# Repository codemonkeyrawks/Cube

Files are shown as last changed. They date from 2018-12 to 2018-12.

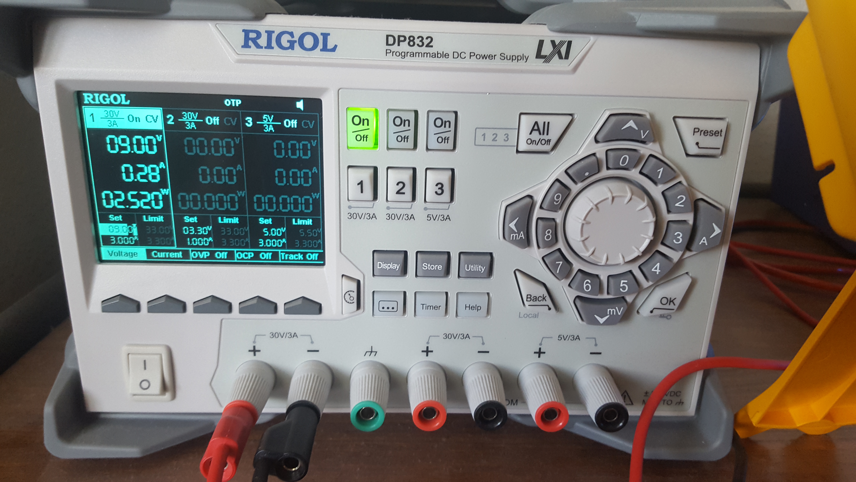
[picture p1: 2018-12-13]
Pics/Issue1PS.jpg

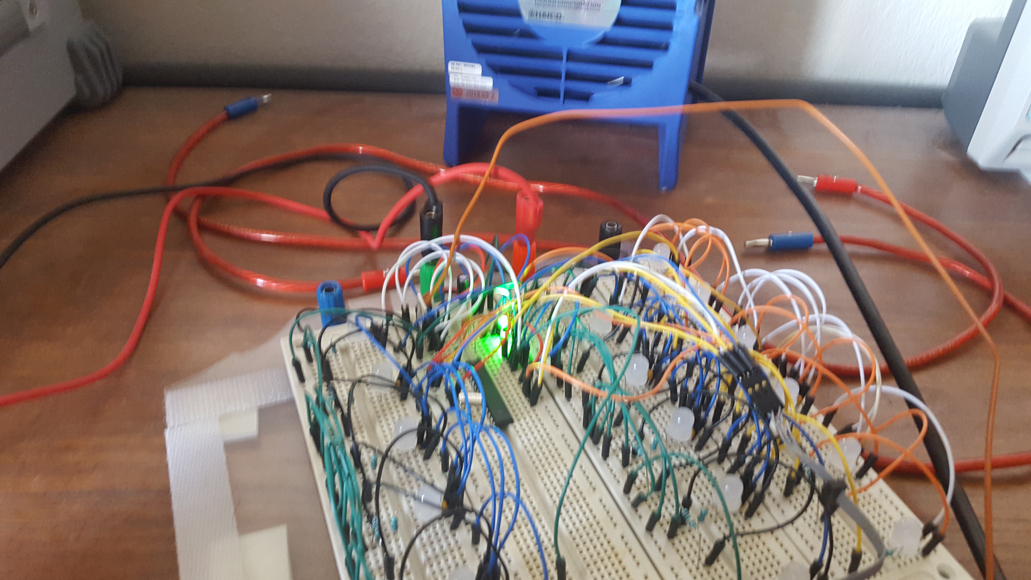
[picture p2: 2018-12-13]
Pics/Issue1Cube.jpg

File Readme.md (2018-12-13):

Led Cube Project:

#### Folder Structure:

    Main Project:
    /CAD - CAD Files for the Cube
    /Circuit - Electrical Hookup Guide
    /Code - TFT Display, Music Board, Lights Code
    /Pics - Pictures of the Build
    /Presentation - Slide Show of Build
    readme.md - Getting Started Guide
    
    Testing:
    .travis.yml - Used for Testing Only (Checks if Code Passes or Not)

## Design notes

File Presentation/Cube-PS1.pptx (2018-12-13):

## Led CUBE Project

By: Brian Holaday

## Past PROJECTS

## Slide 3

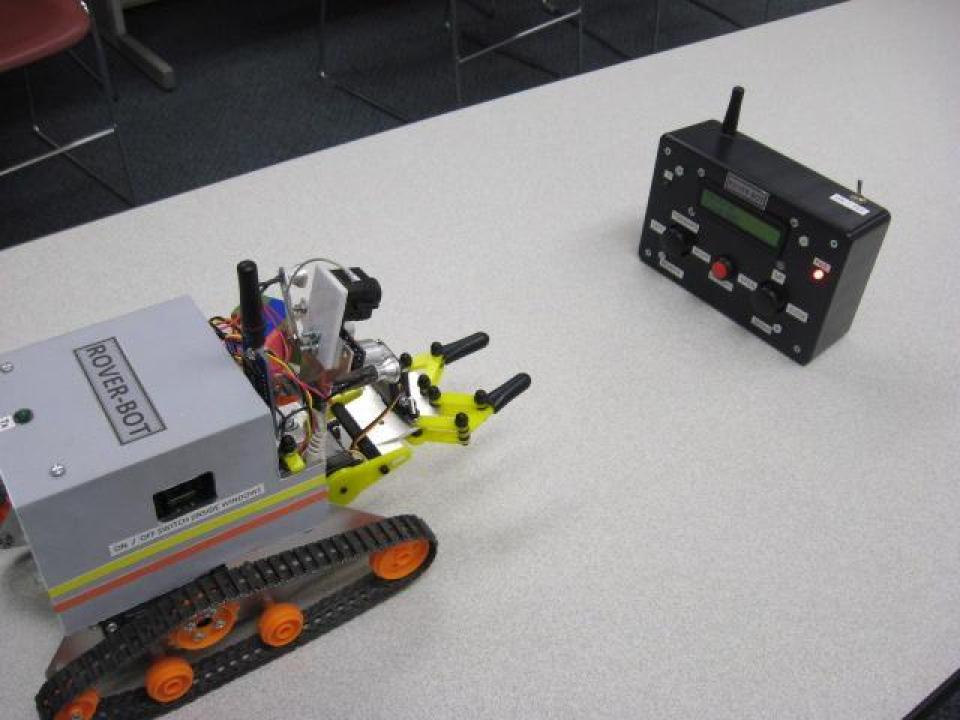
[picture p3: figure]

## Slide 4

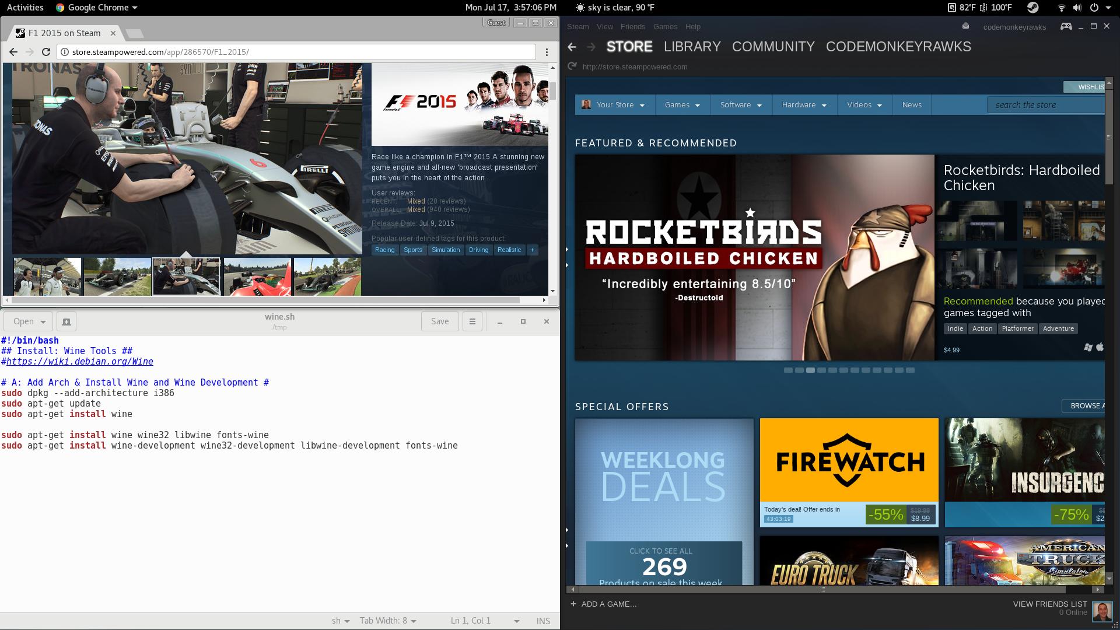
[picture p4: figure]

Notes: https://www.youtube.com/watch?v=Otk6VTVJKBU&list=PL-xZsBalytNA71DNhKQv3fKPJpMA8v7VH&t=0s&index=8 1:34

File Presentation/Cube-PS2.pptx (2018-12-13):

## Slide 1

Led Cube

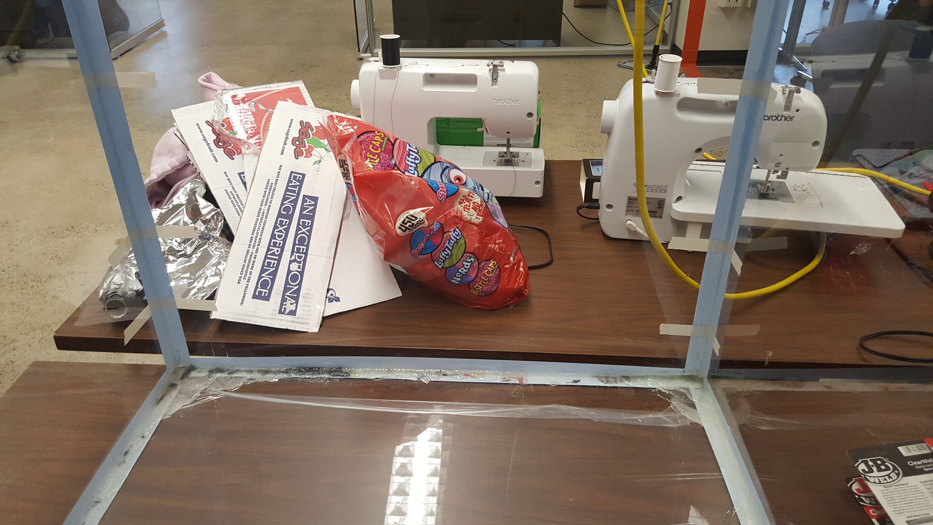
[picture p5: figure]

Description:
Build a 8x8x8 Box with Ping Pong Balls

Brian Holaday

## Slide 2

Led Cube - Problem #1

Problem: Overload on Temperature due to Current

Solution: 6 Volts x 20mA = 120mW (24° C)

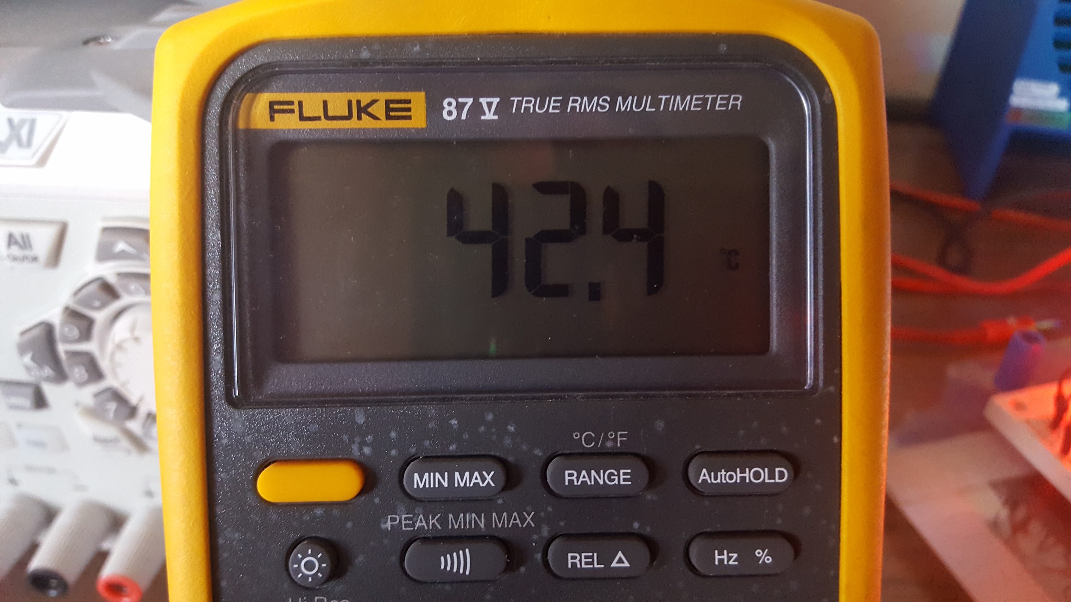
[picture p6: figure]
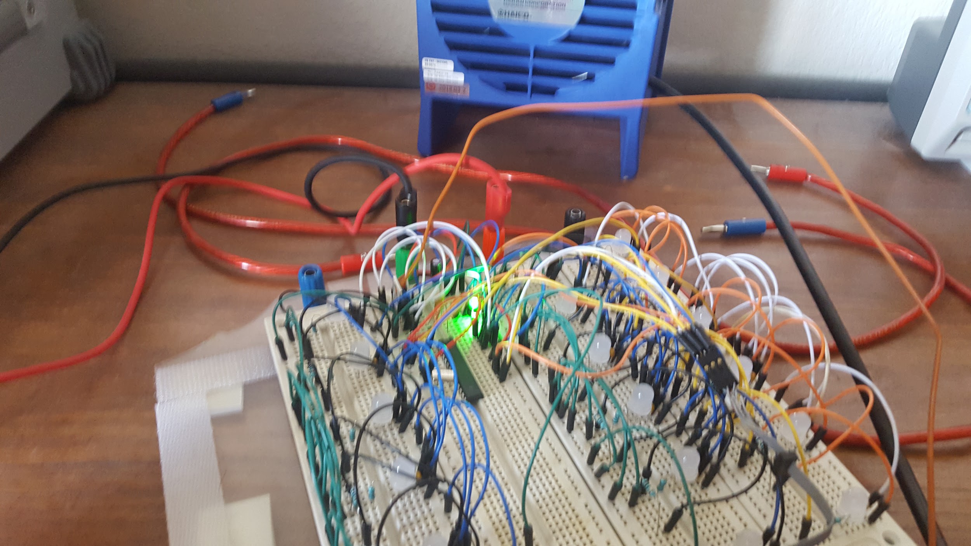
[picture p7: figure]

Brian Holaday

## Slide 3

Led Cube - Problem #2

Problem: Timing is Key with Shift Registers

Solution: Added: RC Filter and R Overload

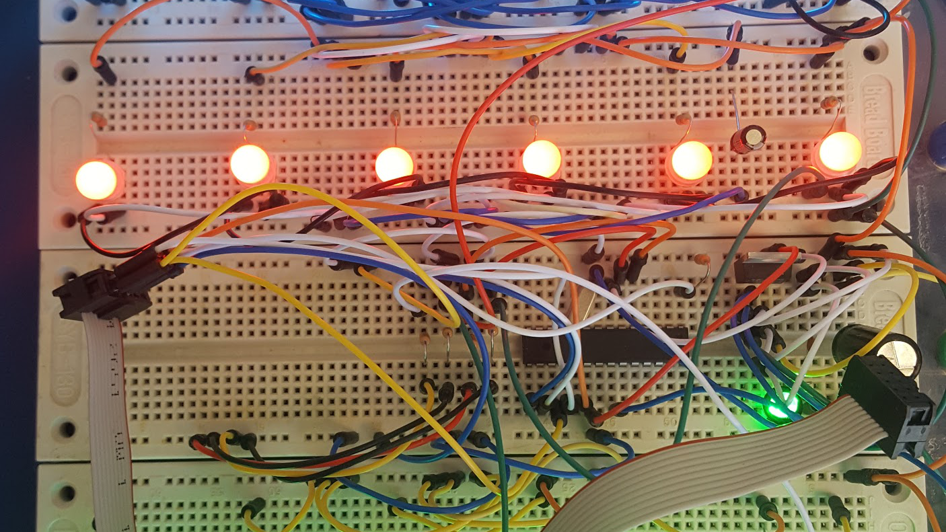
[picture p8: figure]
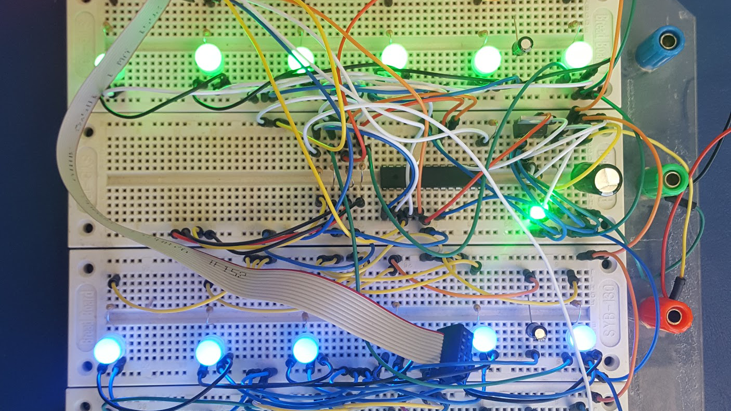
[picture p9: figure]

Brian Holaday

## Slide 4

Led Cube - Problem #3

Problem: Brightness Adjustment using PWM

Solution: Tweaked R Value on LED’s for Max Bright

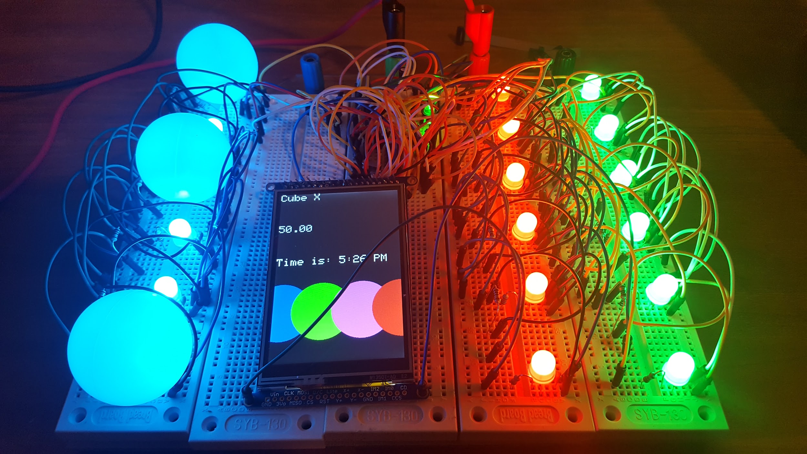
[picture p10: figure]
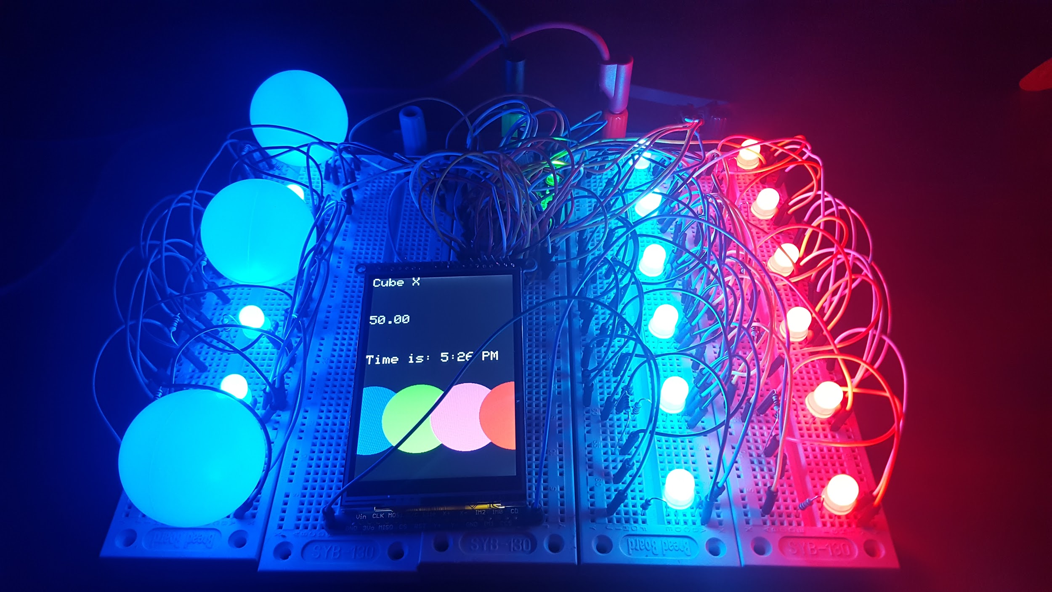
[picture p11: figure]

Brian Holaday

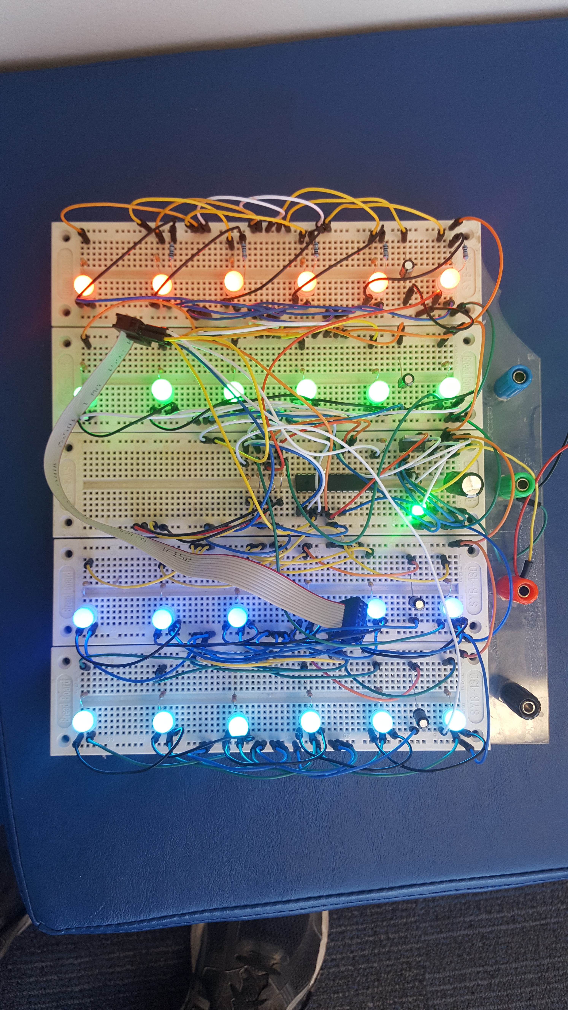
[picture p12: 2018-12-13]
Pics/Led-A.jpg

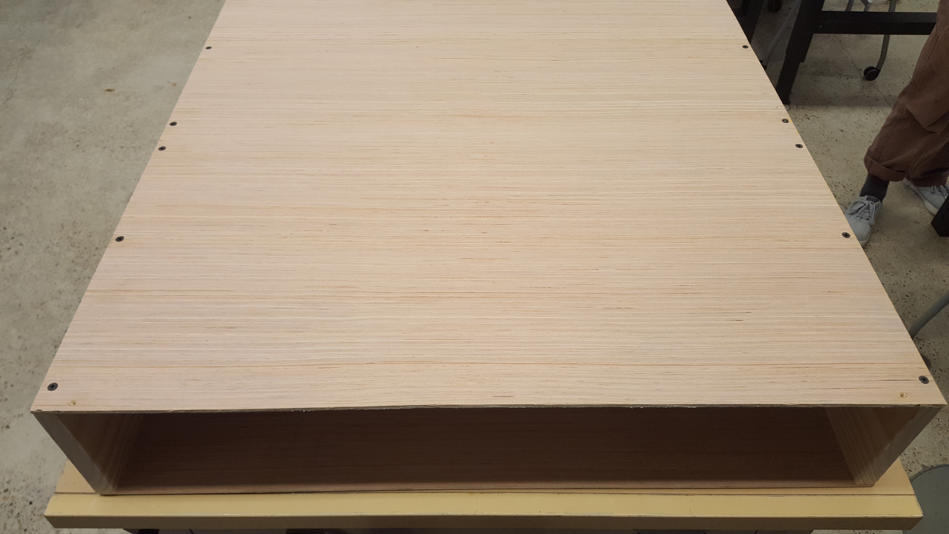
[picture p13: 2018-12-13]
Pics/Base-A.jpg

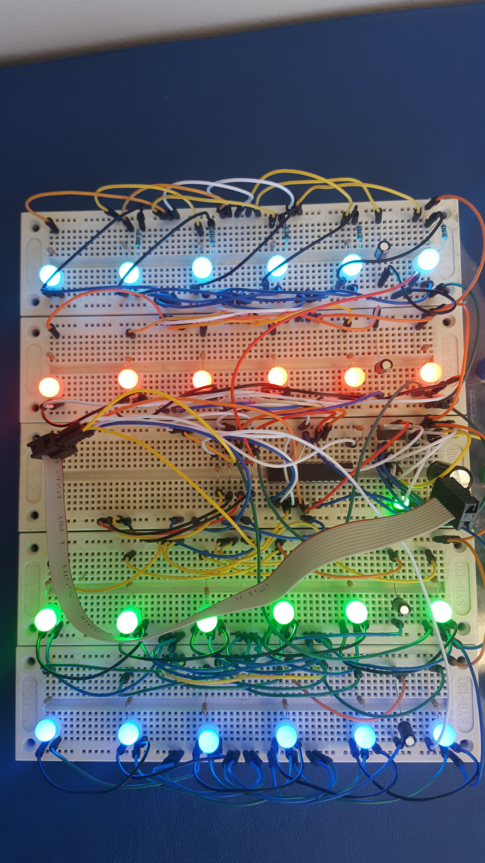
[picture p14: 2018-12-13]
Pics/Led-B.jpg

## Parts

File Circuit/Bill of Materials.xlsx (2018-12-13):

Bill of Materials
Item | Quantity | Cost | Total Cost
Total Cube Cost | 1 | $182.22 | $372.22
Phase #1
LT1083-5 - 5V Regulator (http://www.analog.com/media/en/technical-documentation/data-sheets/1083ffe.pdf) | 8 | $4.20 | $0.00
22uF Tant Cap (https://www.digikey.com/product-detail/en/199D226X9016D1V1E3/718-1182-ND/1559821/?itemSeq=273156367) | 1 | $1.72 | $1.72
10uF Film Cap (https://www.digikey.com/product-detail/en/panasonic-electronic-components/ECA-1HHG100/P5567-ND/245166) | 1 | $0.23 | $0.23
LED | 1 | $0.23 | $0.23 | --
LR1F1K0 - 1K 0.6 W Resistor (https://www.digikey.com/product-detail/en/te-connectivity-passive-product/LR1F1K0/A105951CT-ND/3477524) | 1 | $0.12 | $0.12
3.5mm Jack (https://www.digikey.com/product-detail/en/PJ-002A/CP-002A-ND/96962/?itemSeq=273156850) | 1 | $0.61 | $0.61 | --
Switch - 5A - Slide (https://www.digikey.com/product-detail/en/48ASSP1S3M1QAT/GH7809-ND/2677850/?itemSeq=273157120) | 1 | $3.95 | $3.95 | --
AC/DC Wall Adapter (https://www.digikey.com/product-detail/en/mean-well-usa-inc/SGA60U12-P1J/1866-4550-ND/7706701) | 1 | $24.67 | $24.67 | --
AM2320 - Temp & Humid (https://www.adafruit.com/product/3721) | 2 | $3.95 | $7.90
TMP36 - Temp Sensor (https://www.digikey.com/product-detail/en/analog-devices-inc/TMP36GT9Z/TMP36GT9Z-ND/820404) | 4 | $1.48 | $5.92
5V PWM with Tach FAN (https://www.digikey.com/product-detail/en/delta-electronics/ASB0305HP-00CP4/603-2070-ND/7403227) | 2 | $9.36 | $18.72 | -
Phase #2
ATMEGA 328P-PU (https://www.digikey.com/product-detail/en/microchip-technology/ATMEGA328P-PU/ATMEGA328P-PU-ND/1914589) | 4 | $2.14 | $0.00
PL9823 F8 RGB (https://www.ebay.com/itm/5-1000pcs-DC5V-PL9823-F5-5mm-F8-8mm-round-hat-RGB-LED-Frosted-LED-Chips-P9823/152637379573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) | 520 | $0.16 | $83.20
0.1uF Ceramic Cap (https://www.digikey.com/product-detail/en/K104K15X7RF5TL2/BC1084CT-ND/286706/?itemSeq=273156178) | 520 | 0.06 | $31.20
LR1F10R - 10 Ohm 0.6 W Resistor (https://www.digikey.com/product-detail/en/te-connectivity-passive-product/LR1F10R/A105948CT-ND/3477520) | 520 | $0.02 | $11.17
LR1F100R - 100 Ohm 0.6 W Resistor (https://bit.ly/2EifDAj) | 520 | $0.02 | $11.17
Ping Pong Balls (https://www.amazon.com/Assortmart-Washable-Plastic-Balls-Gross/dp/B0038HUS40) | 4 | $9.29 | $37.16
3/32 Heatshrink Tubing - 100FT (https://bit.ly/2yAaf5B) | 1 | $8.29 | $8.29
Phase #3
LCD Display - 8 Bit 3.5 TFT (https://www.adafruit.com/product/2050) | 1 | $39.95 | $39.95
VS1053 MicroSD Board (https://www.digikey.com/product-detail/en/adafruit-industries-llc/1381/1528-1055-ND/5011071) | 1 | $24.95 | $24.95
22uF Tant Cap (https://www.digikey.com/product-detail/en/199D226X9016D1V1E3/718-1182-ND/1559821/?itemSeq=273156367) | 1 | $1.72 | $1.72
10uF Film Cap (https://www.digikey.com/product-detail/en/panasonic-electronic-components/ECA-1HHG100/P5567-ND/245166) | 1 | $0.23 | $0.23
5mm LED - RGB (https://www.adafruit.com/product/159) | 1 | $0.23 | $0.23
LR1F300R - 330 Ohm 0.6 W Resistor (https://www.digikey.com/product-detail/en/te-connectivity-passive-product/LR1F330R/A105958CT-ND/3477536) | 1 | $0.12 | $0.12
Stereo Speakers - 4 ohms (https://www.digikey.com/product-detail/en/adafruit-industries-llc/1669/1528-1847-ND/6612447) | 1 | $7.50 | $7.50
SD Card - 16GB (https://amzn.to/2IVJtcH) | 3 | $7.12 | $21.36
FeatherWing Ethernet Board (https://bit.ly/2Cc0NbM) | 1 | 19.95 | $19.95
2.8W Amp Breakout Board (https://bit.ly/2NHreZj) | 1 | 9.95 | $9.95

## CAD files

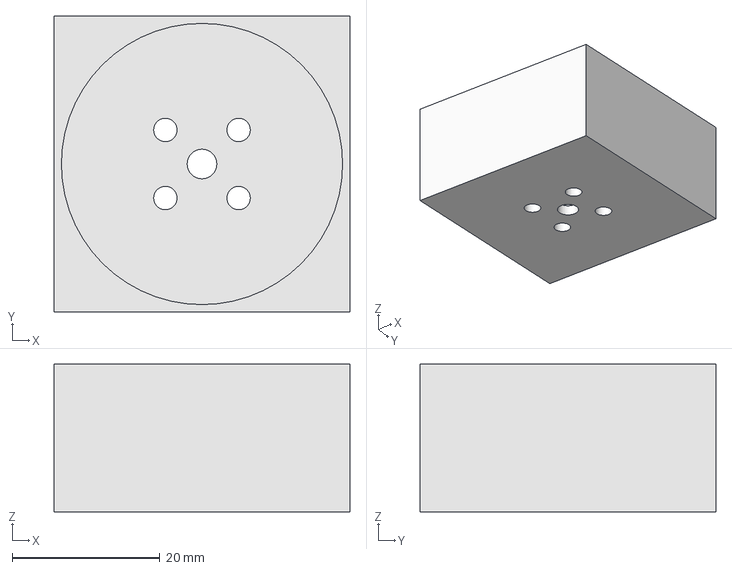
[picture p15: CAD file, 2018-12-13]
CAD/Jig.fcstd
40.0 x 40.0 x 20.0 mm

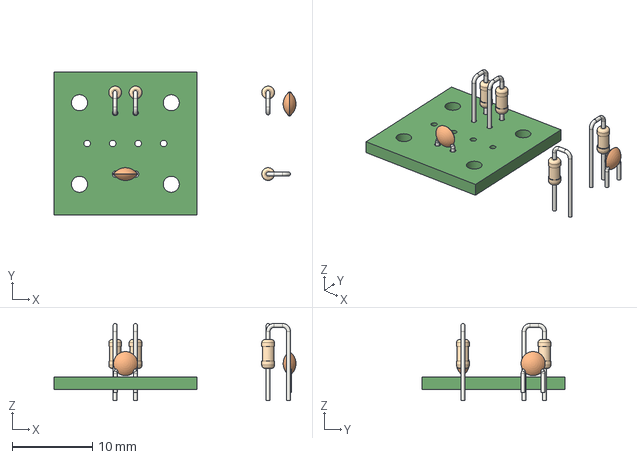
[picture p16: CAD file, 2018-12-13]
Circuit/Balls/Cube-Balls.step
30.1 x 17.8 x 9.60 mm

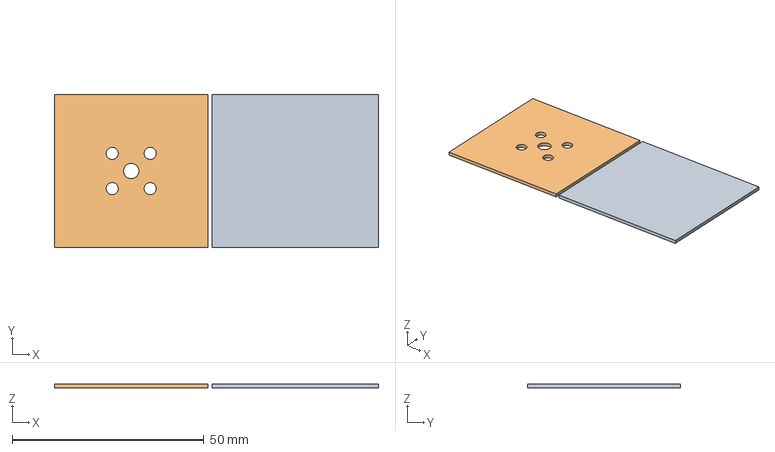
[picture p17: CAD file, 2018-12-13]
CAD/PanelKit.fcstd
84.5 x 40.0 x 1.00 mm

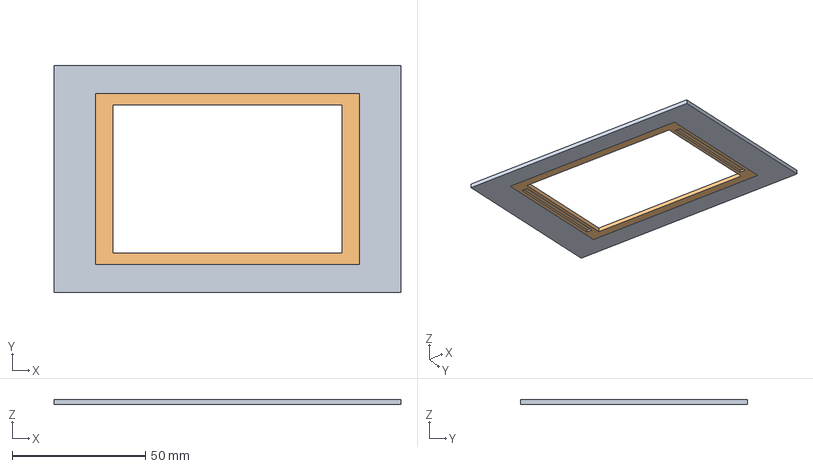
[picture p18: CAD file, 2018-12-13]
CAD/TFT.fcstd
130.0 x 85.0 x 2.00 mm

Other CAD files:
CAD/Jig.stl
CAD/PanelKit.stl
CAD/TFT.stl

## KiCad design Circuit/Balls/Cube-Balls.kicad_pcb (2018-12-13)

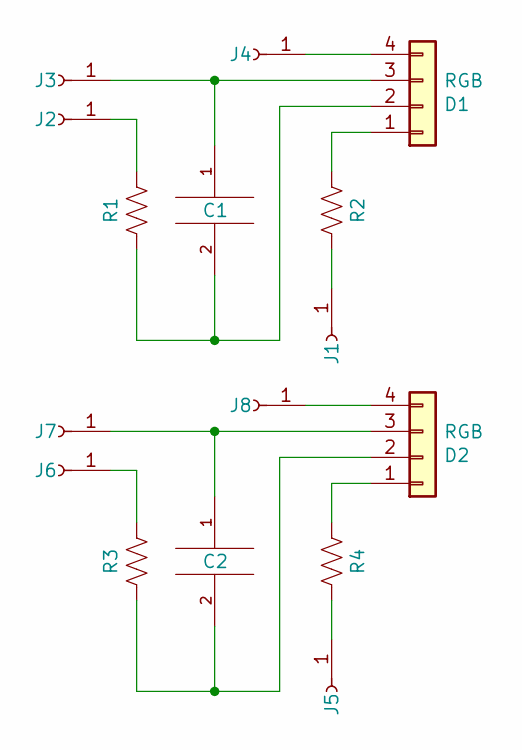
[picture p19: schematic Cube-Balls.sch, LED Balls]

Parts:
C1, C2: 0.1uF; R_Axial_DIN0204_L3.6mm_D1.6mm_P2.54mm_Vertical
D1, D2: RGB; SolderWirePad_1x04_P3.175mm_Drill0.8mm
J1, J5: IN; SolderWirePad_1x01_Drill1mm
J2, J6: VCC; SolderWirePad_1x01_Drill1mm
J3, J7: GND; SolderWirePad_1x01_Drill1mm
J4, J8: OUT; SolderWirePad_1x01_Drill1mm
R1, R3: 100; R_Axial_DIN0204_L3.6mm_D1.6mm_P2.54mm_Vertical
R2, R4: 10; R_Axial_DIN0204_L3.6mm_D1.6mm_P2.54mm_Vertical

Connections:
unnamed: C1.1, D1.3, J3.1
unnamed: C1.2, D1.2, R1.2
unnamed: C2.1, D2.3, J7.1
unnamed: C2.2, D2.2, R3.2
unnamed: D1.1, R2.2
unnamed: D1.4, J4.1
unnamed: D2.1, R4.2
unnamed: D2.4, J8.1
unnamed: J1.1, R2.1
unnamed: J2.1, R1.1
unnamed: J5.1, R4.1
unnamed: J6.1, R3.1

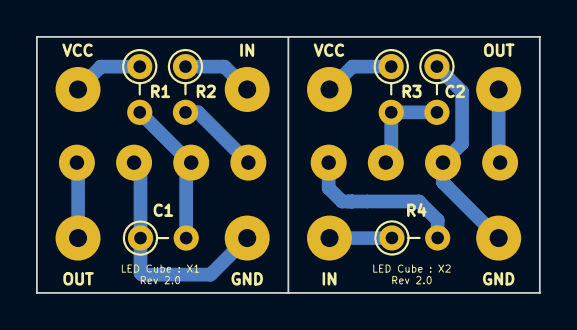
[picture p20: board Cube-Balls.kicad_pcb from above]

Board: 2 copper layers, 27.9 x 14.2 mm, 16 parts (0 on the bottom side), 12 nets.

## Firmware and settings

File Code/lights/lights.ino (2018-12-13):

// Date: 12/13/2018
// Author: Adafruit & (codemonkeyrawks)
// Licence: Creative Commons-Share-Alike-Attribution
// Version: 1.02b-alpha-1

// LED Cube: Functions

// NeoPixel Library
#include <Adafruit_NeoPixel.h>

// LED String Max
#define MAX 8

// Chain: 4 Rows: 4 x 4 Matrix
Adafruit_NeoPixel strip1 = Adafruit_NeoPixel(MAX,4, NEO_RGB + NEO_KHZ400);
Adafruit_NeoPixel strip2 = Adafruit_NeoPixel(MAX,5, NEO_RGB + NEO_KHZ400);
Adafruit_NeoPixel strip3 = Adafruit_NeoPixel(MAX,6, NEO_RGB + NEO_KHZ400);
Adafruit_NeoPixel strip4 = Adafruit_NeoPixel(MAX,7, NEO_RGB + NEO_KHZ400);

void setup() {

  // Init: Strip #1
  strip1.begin();
  strip1.show();
  delay(20);

  // Init: Strip #2
  strip2.begin();
  strip2.show();

  // Init: Strip #3
  strip3.begin();
  strip3.show();

  // Init: Strip #4
  strip4.begin();
  strip4.show();

  pinMode(13, OUTPUT);

}

void loop() {

  // Red
  strip1.setPixelColor(0,255,0,0);
  strip1.setPixelColor(1,255,0,0);
  strip1.setPixelColor(2,255,0,0);
  strip1.setPixelColor(3,255,0,0);
  strip1.setPixelColor(4,255,0,0);
  strip1.setPixelColor(5,255,0,0);
  strip1.show();
  delay(1000);

  // Orange
  strip1.setPixelColor(0,255,128,0);
  strip1.setPixelColor(1,255,128,0);
  strip1.setPixelColor(2,255,128,0);
  strip1.setPixelColor(3,255,128,0);
  strip1.setPixelColor(4,255,128,0);
  strip1.setPixelColor(5,255,128,0);
  strip1.show();
  delay(1000);

  // Yellow
  strip1.setPixelColor(0,255,255,0);
  strip1.setPixelColor(1,255,255,0);
  strip1.setPixelColor(2,255,255,0);
  strip1.setPixelColor(3,255,255,0);
  strip1.setPixelColor(4,255,255,0);
  strip1.setPixelColor(5,255,255,0);
  strip1.show();
  delay(1000);
  
  // Green
  strip1.setPixelColor(0,0,255,0);
  strip1.setPixelColor(1,0,255,0);
  strip1.setPixelColor(2,0,255,0);
  strip1.setPixelColor(3,0,255,0);
  strip1.setPixelColor(4,0,255,0);
  strip1.setPixelColor(5,0,255,0);
  strip1.show();
  delay(1000);

  // Blue
  strip1.setPixelColor(0,0,0,255);
  strip1.setPixelColor(1,0,0,255);
  strip1.setPixelColor(2,0,0,255);
  strip1.setPixelColor(3,0,0,255);
  strip1.setPixelColor(4,0,0,255);
  strip1.setPixelColor(5,0,0,255);
  strip1.show();
  delay(1000);

  // Indigo
  strip1.setPixelColor(0,255,255,0);
  strip1.setPixelColor(1,255,255,0);
  strip1.setPixelColor(2,255,255,0);
  strip1.setPixelColor(3,255,255,0);
  strip1.setPixelColor(4,255,255,0);
  strip1.setPixelColor(5,255,255,0);
  strip1.show();
  delay(1000);

  // Violet
  strip1.setPixelColor(0,255,0,255);
  strip1.setPixelColor(1,255,0,255);
  strip1.setPixelColor(2,255,0,255);
  strip1.setPixelColor(3,255,0,255);
  strip1.setPixelColor(4,255,0,255);
  strip1.setPixelColor(5,255,0,255);
  strip1.show();
  delay(1000);

  for (int x = 0; x <= MAX; x++) {
    strip1.setPixelColor(x,0,0,0);
    strip1.show();
    delay(300);
  }

  //////////////////////

  for (int x = 6; x >= 0; x--) {
    strip1.setPixelColor(x,255,0,0);
    strip1.show();
    delay(300);
  }

  for (int x = 6; x >= 0; x--) {
    strip1.setPixelColor(x,0,0,0);
    strip1.show();
    delay(300);
  }

  for (int x = 0; x <= MAX; x++) {
    strip1.setPixelColor(x,255,0,0);
    strip1.show();
    delay(300);
  }

  //////////////////////

  for (int x = 0; x <= MAX; x++) {
    strip1.setPixelColor(x,0,0,0);
    strip1.show();
    delay(300);
  }

  for (int x = 6; x >= 0; x--) {
    strip1.setPixelColor(x,255,128,0);
    strip1.show();
    delay(300);
  }

  for (int x = 6; x >= 0; x--) {
    strip1.setPixelColor(x,0,0,0);
    strip1.show();
    delay(300);
  }

  for (int x = 0; x <= MAX; x++) {
    strip1.setPixelColor(x,255,128,0);
    strip1.show();
    delay(300);
  }

  //////////////////////

  for (int x = 0; x <= MAX; x++) {
    strip1.setPixelColor(x,0,0,0);
    strip1.show();
    delay(300);
  }

  for (int x = 6; x >= 0; x--) {
    strip1.setPixelColor(x,255,255,0);
    strip1.show();
    delay(300);
  }

  for (int x = 6; x >= 0; x--) {
    strip1.setPixelColor(x,0,0,0);
    strip1.show();
    delay(300);
  }

  for (int x = 0; x <= MAX; x++) {
    strip1.setPixelColor(x,255,255,0);
    strip1.show();
    delay(300);
  }

  //////////////////////

  for (int x = 0; x <= MAX; x++) {
    strip1.setPixelColor(x,0,0,0);
    strip1.show();
    delay(300);
  }

  for (int x = 6; x >= 0; x--) {
    strip1.setPixelColor(x,0,255,0);
    strip1.show();
    delay(300);
  }

  for (int x = 6; x >= 0; x--) {
    strip1.setPixelColor(x,0,0,0);
    strip1.show();
    delay(300);
  }

  for (int x = 0; x <= MAX; x++) {
    strip1.setPixelColor(x,0,255,0);
    strip1.show();
    delay(300);
  }

  //////////////////////

  for (int x = 0; x <= MAX; x++) {
    strip1.setPixelColor(x,0,0,0);
    strip1.show();
    delay(300);
  }

  for (int x = 6; x >= 0; x--) {
    strip1.setPixelColor(x,0,0,255);
    strip1.show();
    delay(300);
  }

  for (int x = 6; x >= 0; x--) {
    strip1.setPixelColor(x,0,0,0);
    strip1.show();
    delay(300);
  }

  for (int x = 0; x <= MAX; x++) {
    strip1.setPixelColor(x,0,0,255);
    strip1.show();
    delay(300);
  }

    //////////////////////

  for (int x = 0; x <= MAX; x++) {
    strip1.setPixelColor(x,0,0,0);
    strip1.show();
    delay(300);
  }

  for (int x = 6; x >= 0; x--) {
    strip1.setPixelColor(x,255,255,0);
    strip1.show();
    delay(300);
  }

  for (int x = 6; x >= 0; x--) {
    strip1.setPixelColor(x,0,0,0);
    strip1.show();
    delay(300);
  }

  for (int x = 0; x <= MAX; x++) {
    strip1.setPixelColor(x,255,255,0);
    strip1.show();
    delay(300);
  }

  //////////////////////

  for (int x = 0; x <= MAX; x++) {
    strip1.setPixelColor(x,0,0,0);
    strip1.show();
    delay(300);
  }

  for (int x = 6; x >= 0; x--) {
    strip1.setPixelColor(x,255,0,255);
    strip1.show();
    delay(300);
  }

  for (int x = 6; x >= 0; x--) {
    strip1.setPixelColor(x,0,0,0);
    strip1.show();
    delay(300);
  }

  for (int x = 0; x <= MAX; x++) {
    strip1.setPixelColor(x,255,0,255);
    strip1.show();
    delay(300);
  }

  for (int x = 0; x <= MAX; x++) {
    strip1.setPixelColor(x,0,0,0);
    strip1.show();
  }

  strip1.setPixelColor(0,255,0,0);
  strip1.show();
  delay(300);
  strip1.setPixelColor(1,255,128,0);
  strip1.show();
  delay(300);
  strip1.setPixelColor(2,255,255,0);
  strip1.show();
  delay(300);
  strip1.setPixelColor(3,0,255,0);
  strip1.show();
  delay(300);
  strip1.setPixelColor(4,0,0,255);
  strip1.show();
  delay(300);
  strip1.setPixelColor(5,255,0,255);
  strip1.show();
  delay(300);
  
  delay(5000);
}

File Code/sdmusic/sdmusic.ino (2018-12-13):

// Date: 12/13/2018
// Author: Adafruit & (codemonkeyrawks)
// Licence: Creative Commons-Share-Alike-Attribution
// Version: 1.02b-alpha-1

// SPI, MP3, SD Card: VS1053
// Serial: MIDI VS1053
#include <SPI.h>
#include <Adafruit_VS1053.h>
#include <SD.h>
#include <SoftwareSerial.h>

// VS1053: PIN Layout
#define VS1053_RX  2     // MIDI PIN
#define VS1053_DREQ 3    // Interrup
#define VS1053_CARDCS 4  // Chip Select: SD Card
#define VS1053_DCS 8     // Data Select
#define VS1053_RESET 9   // Reset: Not Used
#define VS1053_CS 10     // Chip Select: VS1053
#define POT A5

// VS1053: MIDI/User Options
#define VS1053_BANK_DEFAULT 0x00
#define VS1053_BANK_DRUMS1 0x78
#define VS1053_BANK_DRUMS2 0x7F
#define VS1053_BANK_MELODY 0x79
#define VS1053_GM1_OCARINA 80
#define MIDI_NOTE_ON  0x90
#define MIDI_NOTE_OFF 0x80
#define MIDI_CHAN_MSG 0xB0
#define MIDI_CHAN_BANK 0x00
#define MIDI_CHAN_VOLUME 0x07
#define MIDI_CHAN_PROGRAM 0xC0

// USER Defined 

// VS1053: Init Player
Adafruit_VS1053_FilePlayer musicPlayer =
Adafruit_VS1053_FilePlayer(VS1053_RESET, VS1053_CS, VS1053_DCS, VS1053_DREQ, VS1053_CARDCS);

// VS1053: Init MIDI
SoftwareSerial VS1053_MIDI(0, 2);

void setup() {

  // AMP Startup Section //
  // Define: PIN DEF
  pinMode(0, OUTPUT);
  pinMode(1, OUTPUT);
  
  // MIDI Control: HIGH: OFF, LOW: ON
  pinMode(5, OUTPUT);

  delay(500);

  // Flash LED if Chip is not found!
  if (! musicPlayer.begin()) {
    digitalWrite(7, HIGH);
    delay(100);
    digitalWrite(7, LOW);
    delay(100);
  }

  // Flash LED if SD is not found!
  if (!SD.begin(VS1053_CARDCS)) {
    digitalWrite(7, HIGH);
    delay(300);
    digitalWrite(7, LOW);
    delay(300);
  }

  // VS1053 Startup Section //
  VS1053_MIDI.begin(31250);

}

void loop() { 
  setMIDI();
  setMP3();
}

// User Passes MP3 Files
void setMP3() {

  // Scan Volume
  setMP3Vol();

  // MIDI: LOW, SD: HIGH
  digitalWrite(5, LOW);
  delay(500);
  
  musicPlayer.useInterrupt(VS1053_FILEPLAYER_PIN_INT);
  musicPlayer.startPlayingFile("track01.mp3");

  for (int x = 0; x < 60; x++) {
      setMP3Vol();
    delay(250);
  }

  musicPlayer.stopPlaying();
  delay(100);

  musicPlayer.useInterrupt(VS1053_FILEPLAYER_PIN_INT);
  musicPlayer.startPlayingFile("track02.mp3");
  
  for (int x = 0; x < 60; x++) {
      setMP3Vol();
    delay(250);
  }

  musicPlayer.stopPlaying();
  delay(100);

  musicPlayer.useInterrupt(VS1053_FILEPLAYER_PIN_INT);
  musicPlayer.startPlayingFile("track03.mp3");
  
  for (int x = 0; x < 60; x++) {
      setMP3Vol();
    delay(250);
  }

  musicPlayer.stopPlaying();
  delay(100);

  // Disable: AMP
  disableAMP();

  // Wait for IC to Clear
  musicPlayer.softReset();
  delay(500);
}

//User Passes MIDI Note
void setMIDI() {

  // Scan Volume
  setMIDVol();

  // MIDI: LOW, SD: HIGH
  digitalWrite(5, HIGH);
  delay(500);

  // MIDI: BANKS
  midiSetChannelBank(0, VS1053_BANK_MELODY);
  midiSetInstrument(0, VS1053_GM1_OCARINA);

  for (uint8_t i=60; i<69; i++) {
    midiNoteOn(0, i, 127);
    delay(100);
    midiNoteOff(0, i, 127);
  }

  delay(100);

  // Disable: AMP
  disableAMP();

  // Wait for IC to Clear
  musicPlayer.softReset();
  delay(500);
  
}

void setMP3Vol() {

  // Read POT Value
  int PO = analogRead(POT);
  delay(20);

  // Set Volume: Scale 0 - 10 x 2
  for (int x = 0; x <= 10; x++) {
    // Range: 1020 / 10 = 51.05
    int calc1 = 102 * x;
    int calc2 = (102 * (x + 1));
    if (x > 9) {
      disableAMP();
      break;
    }
    else if ((PO >= calc1) && (PO <= calc2)) {
      enableAMP();
      musicPlayer.setVolume(x+x,x+x);
      break;
    }
  }
}

void setMIDVol() {
  // Read POT Value
  int PO = analogRead(POT);
  delay(20);

  // Set Volume: Scale 0 - 120
  for (int x = 0; x <= 120; x++) {
    // Range: 1020 / 120 = 8.53
    int calc1 = 8.53 * x;
    int calc2 = (8.53 * (x + 1));
    if (x > 100) {
      disableAMP();
      break;
    }
    else if ((PO >= calc1) && (PO <= calc2)) {
      enableAMP();
      midiSetChannelVolume(x, x);
      break;
    }
  }
}

void disableAMP() {
  musicPlayer.setVolume(20,20);
  midiSetChannelVolume(0, 0);
  digitalWrite(0,LOW);
  digitalWrite(1,LOW);
}

void enableAMP() {
  digitalWrite(0,HIGH);
  digitalWrite(1,HIGH);
}

void midiSetInstrument(uint8_t chan, uint8_t inst) {
  if (chan > 15) return;
  inst --; // page 32 has instruments starting with 1 not 0 :(
  if (inst > 127) return;
  
  VS1053_MIDI.write(MIDI_CHAN_PROGRAM | chan);  
  VS1053_MIDI.write(inst);
}


void midiSetChannelVolume(uint8_t chan, uint8_t vol) {
  if (chan > 15) return;
  if (vol > 127) return;
  
  VS1053_MIDI.write(MIDI_CHAN_MSG | chan);
  VS1053_MIDI.write(MIDI_CHAN_VOLUME);
  VS1053_MIDI.write(vol);
}

void midiSetChannelBank(uint8_t chan, uint8_t bank) {
  if (chan > 15) return;
  if (bank > 127) return;
  
  VS1053_MIDI.write(MIDI_CHAN_MSG | chan);
  VS1053_MIDI.write((uint8_t)MIDI_CHAN_BANK);
  VS1053_MIDI.write(bank);
}

void midiNoteOn(uint8_t chan, uint8_t n, uint8_t vel) {
  if (chan > 15) return;
  if (n > 127) return;
  if (vel > 127) return;
  
  VS1053_MIDI.write(MIDI_NOTE_ON | chan);
  VS1053_MIDI.write(n);
  VS1053_MIDI.write(vel);
}

void midiNoteOff(uint8_t chan, uint8_t n, uint8_t vel) {
  if (chan > 15) return;
  if (n > 127) return;
  if (vel > 127) return;
  
  VS1053_MIDI.write(MIDI_NOTE_OFF | chan);
  VS1053_MIDI.write(n);
  VS1053_MIDI.write(vel);
}

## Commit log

2018-11-28 Add: TFT Display: Sample
2018-12-13 Init: LED Cube Code
    [Bill of Materials.xlsx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]
